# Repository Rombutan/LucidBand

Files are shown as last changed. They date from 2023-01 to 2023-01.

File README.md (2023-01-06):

# LucidBand! - The really thin, no-charge smartwatch.
## Philosophy
I quite like the idea of having lots of easily accessible data about myself. Fitness and biological data can be a big help in organizing and optimizing one's life, and I think everyone should have access to that data about *themselves*. 
I want something really thin and somewhat modular that can collect a lot of the data I want to have access to.

## Technology
LucidBand hasa flexible solar cell and everything but the display in the wristband!
The only thing in the face is the display - everything else is on a pcb built into the bottom of the wristband (under your wrist). This lets the face be really thin - hopefully around 7mm - and also allows operation without the display (think: ankle band).
The band will be cast out of a semi-flexible clear epoxy or something.

## Chips
* MCU:			ESP32-C3-WROOM-02-N4
* ENERGY:	  BQ25504
* GYRO:		  BMI270
* SOLAR:		ONP2.4-15X94
<br>
BOM cost for 5 boards with shipping to California turned up to be around 150$. I'm guessing parts for only 1 board would be around 100$ with shipping.

## Screenshots
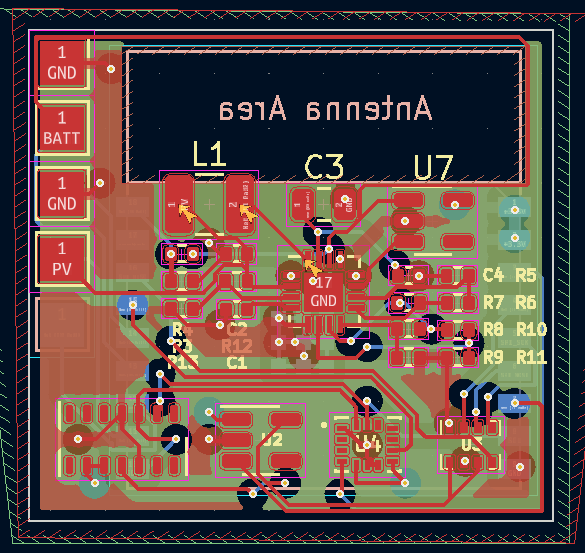
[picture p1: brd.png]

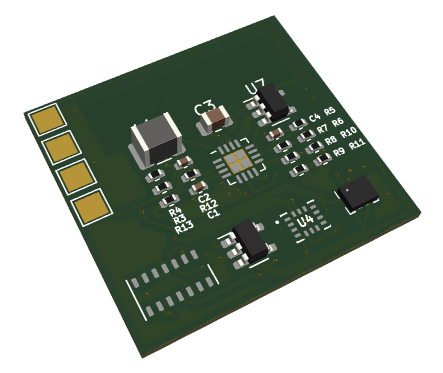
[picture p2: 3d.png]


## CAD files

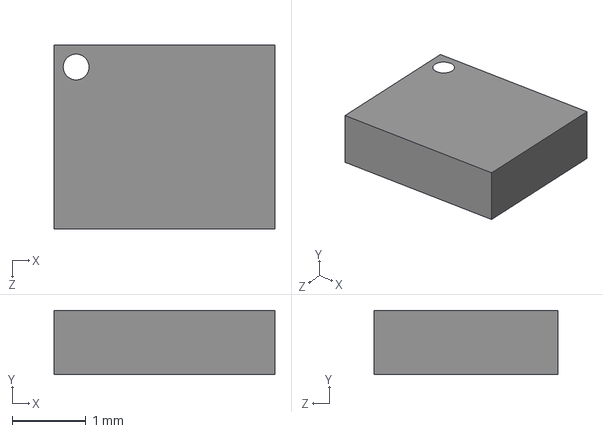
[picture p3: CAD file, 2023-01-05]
kicad-libs/BMI270/BMI270.step
3.00 x 0.87 x 2.50 mm

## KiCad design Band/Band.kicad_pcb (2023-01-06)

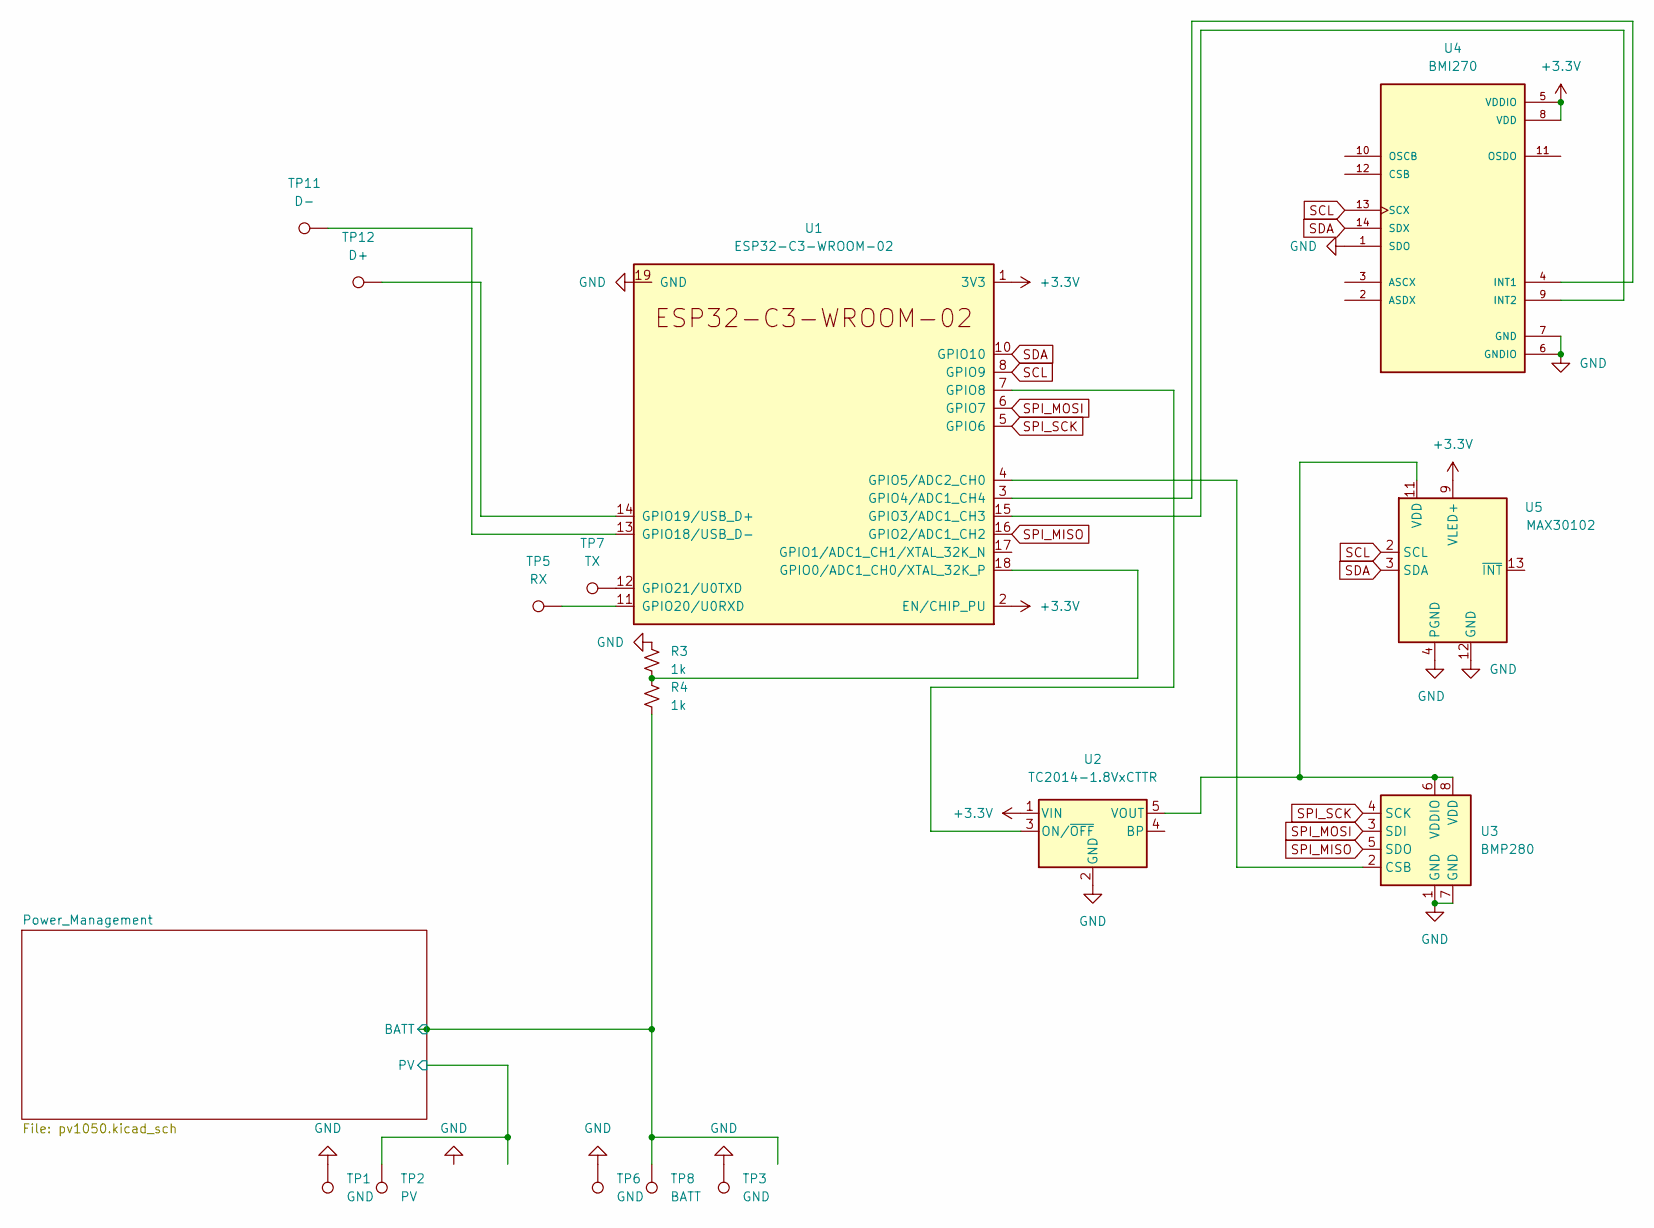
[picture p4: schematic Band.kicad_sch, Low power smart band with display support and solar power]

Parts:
R3, R4: 1k; R_0402_1005Metric
TP1, TP3, TP6: GND; TestPoint_Pad_2.0x2.0mm
TP2: PV; TestPoint_Pad_2.0x2.0mm
TP5: RX; TestPoint_Pad_2.0x2.0mm
TP7: TX; TestPoint_Pad_2.0x2.0mm
TP8: BATT; TestPoint_Pad_2.0x2.0mm
TP11: D-; TestPoint_Pad_2.0x2.0mm
TP12: D+; TestPoint_Pad_2.0x2.0mm
U1: ESP32-C3-WROOM-02
U2: TC2014-1.8VxCTTR; SOT-23-5
U3: BMP280; Bosch_LGA-8_2x2.5mm_P0.65mm_ClockwisePinNumbering
U4: BMI270; XDCR_BMI270
U5: MAX30102; Maxim_OLGA-14_3.3x5.6mm_P0.8mm

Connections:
+3.3V: U1.1 (3V3), U1.2 (EN/CHIP_PU), U2.1 (VIN), U4.5 (VDDIO), U4.8 (VDD), U5.9 (VLED+), U5.10 (VLED+); also elsewhere on the board
/Power_Management/BATT: R4.2, TP8.1; also elsewhere on the board
/Power_Management/PV: TP2.1; also elsewhere on the board
GND: R3.1, TP1.1, TP3.1, TP6.1, U1.9 (GND), U1.19 (GND), U2.2 (GND), U3.1 (GND), U3.7 (GND), U4.1 (SDO), U4.6 (GNDIO), U4.7 (GND), U5.4 (PGND), U5.12 (GND); also elsewhere on the board
unnamed: R3.2, R4.1, U1.18 (GPIO0/ADC1_CH0/XTAL_32K_P)
unnamed: TP5.1, U1.11 (GPIO20/U0RXD)
unnamed: TP7.1, U1.12 (GPIO21/U0TXD)
unnamed: U1.3 (GPIO4/ADC1_CH4), U4.4 (INT1)
unnamed: U1.4 (GPIO5/ADC2_CH0), U3.2 (CSB)
unnamed: U1.7 (GPIO8), U2.3 (ON/~OFF)
unnamed: TP11.1, U1.13 (GPIO18/USB_D-)
unnamed: TP12.1, U1.14 (GPIO19/USB_D+)
unnamed: U1.15 (GPIO3/ADC1_CH3), U4.9 (INT2)
unnamed: U2.5 (VOUT), U3.6 (VDDIO), U3.8 (VDD), U5.11 (VDD)
SCL: U1.8 (GPIO9), U4.13 (SCX), U5.2 (SCL)
SDA: U1.10 (GPIO10), U4.14 (SDX), U5.3 (SDA)
SPI_MISO: U1.16 (GPIO2/ADC1_CH2), U3.5 (SDO)
SPI_MOSI: U1.6 (GPIO7), U3.3 (SDI)
SPI_SCK: U1.5 (GPIO6), U3.4 (SCK)

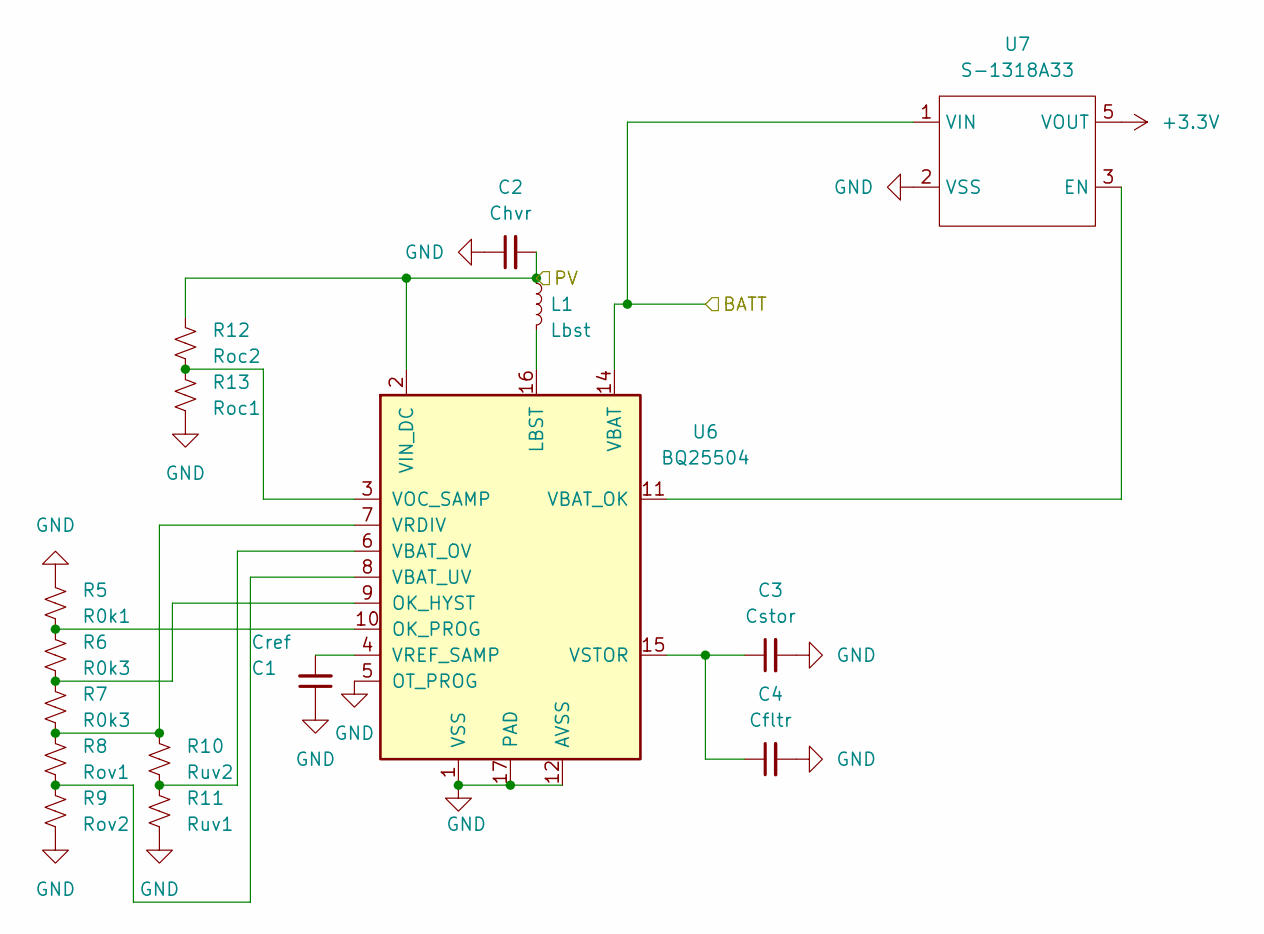
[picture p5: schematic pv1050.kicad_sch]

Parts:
C1: Cref; C_0402_1005Metric
C2: Chvr; C_0402_1005Metric
C3: Cstor; C_0805_2012Metric
C4: Cfltr; C_0402_1005Metric
L1: Lbst; L_1210_3225Metric
R5: R0k1; R_0402_1005Metric
R6, R7: R0k3; R_0402_1005Metric
R8: Rov1; R_0402_1005Metric
R9: Rov2; R_0402_1005Metric
R10: Ruv2; R_0402_1005Metric
R11: Ruv1; R_0402_1005Metric
R12: Roc2; R_0402_1005Metric
R13: Roc1; R_0402_1005Metric
U6: BQ25504; VQFN-16-1EP_3x3mm_P0.5mm_EP1.8x1.8mm
U7: S-1318A33; SOT-23-5

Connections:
+3.3V: U7.5 (VOUT); also elsewhere on the board
/Power_Management/BATT: U6.14 (VBAT), U7.1 (VIN); also elsewhere on the board
/Power_Management/PV: C2.2, L1.1, R12.1, U6.2 (VIN_DC); also elsewhere on the board
GND: C1.1, C2.1, C3.2, C4.2, R5.1, R9.2, R11.2, R13.2, U6.1 (VSS), U6.5 (OT_PROG), U6.12 (AVSS), U6.13 (VSS), U6.17 (PAD), U7.2 (VSS); also elsewhere on the board
unnamed: C1.2, U6.4 (VREF_SAMP)
unnamed: C3.1, C4.1, U6.15 (VSTOR)
unnamed: L1.2, U6.16 (LBST)
unnamed: R5.2, R6.1, U6.10 (OK_PROG)
unnamed: R6.2, R7.1, U6.9 (OK_HYST)
unnamed: R8.2, R9.1, U6.8 (VBAT_UV)
unnamed: R7.2, R8.1, R10.1, U6.7 (VRDIV)
unnamed: R10.2, R11.1, U6.6 (VBAT_OV)
unnamed: R12.2, R13.1, U6.3 (VOC_SAMP)
unnamed: U6.11 (VBAT_OK), U7.3 (EN)

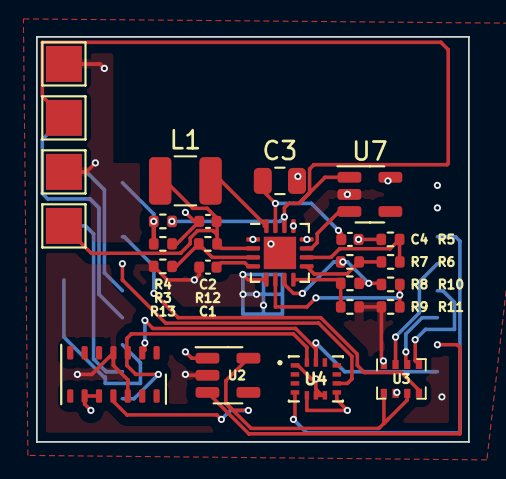
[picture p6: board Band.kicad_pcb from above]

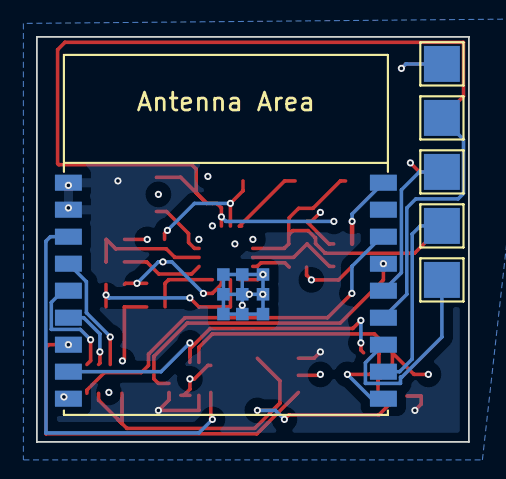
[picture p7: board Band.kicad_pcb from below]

Board: 4 copper layers, 24.0 x 22.5 mm, 32 parts (6 on the bottom side), 29 nets.

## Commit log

2021-03-21 add sensors.txt
2021-03-21 add mainboard PCB files
    [MainBoard.kicad_pcb, MainBoard.sch]
2021-03-22 add PV supply circuit
    [MainBoard.sch]
2021-03-24 add final sensors and update PCB
    [MainBoard.kicad_pcb, MainBoard.sch]
2021-03-26 lots of work on PCB
    [MainBoard.kicad_pcb, MainBoard.sch]
2021-03-28 clean silkscreen, add power delivery, route LoRa RF
    [MainBoard.kicad_pcb, MainBoard.sch]
2021-03-28 add pdfs
    [MainBoard.kicad_pcb, MainBoard.sch]
2021-03-28 flip LoRa TX stuff to deduce footprint and track length, update pdfs
    [MainBoard.kicad_pcb]
2021-03-31 ditch LoRa, switch processor to STM32WB30CE
    [MainBoard.kicad_pcb, MainBoard.sch]
2021-03-31 route entire damn thing in one sitting
    [MainBoard.kicad_pcb, MainBoard.sch]
2021-03-31 add crystal, pour ground plane
    [MainBoard.csv, MainBoard.kicad_pcb, MainBoard.sch]
2021-05-06 many, many things :)
    [MainBoard.kicad_pcb]
2021-05-06 add programming/charging dock board
    [Dock.kicad_pcb, Dock.sch]
2021-05-07 export gerbers
    [MainBoard.kicad_pcb]
2021-05-18 add accelerometer and thicken switch traces
    [MainBoard.kicad_pcb, MainBoard.sch]
2021-05-18 Update images
    [FingerBoard.kicad_pcb, FingerBoard.sch, MuxBoard.kicad_pcb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]
2021-05-22 I dont even remember
    [Dock-B_Cu.gbr, Dock-B_Mask.gbr, Dock-B_Paste.gbr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]
2021-05-30 switch processor, add sensors, change shape'
    [MainBoard.kicad_pcb, MainBoard.sch]
2021-05-31 update pdf's
    [MainBoard.kicad_pcb, MainBoard.sch]
2021-05-31 remove old stuffs
    [Dock-B_Cu.gbr, Dock-B_Mask.gbr, Dock-B_Paste.gbr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]
2021-05-31 update images for README
    [MainBoard.kicad_pcb]
2021-05-31 oops! I forgot the buzzer
    [MainBoard.kicad_pcb, MainBoard.sch]
2021-06-04 route board
    [MainBoard.kicad_pcb, MainBoard.sch]
2023-01-05 make readme and decide hardware
    [MainBoard-B_Cu.gbr, MainBoard-B_Mask.gbr, MainBoard-B_Paste.gbr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]
2023-01-05 goofy submodule won't die
2023-01-05 init pcb commit
    [BMI270.step, Band.kicad_sch, pv1050.kicad_sch]
2023-01-05 finish schematic
    [Band.kicad_pcb, Band.kicad_sch, pv1050.kicad_sch]
2023-01-05 preliminary layout
    [Band.kicad_pcb, Band.kicad_sch, pv1050.kicad_sch]
2023-01-06 finish layout and route
    [Band.kicad_pcb]
2023-01-06 v1 final changes
    [Band.kicad_pcb, Band.kicad_sch, pv1050.kicad_sch]
